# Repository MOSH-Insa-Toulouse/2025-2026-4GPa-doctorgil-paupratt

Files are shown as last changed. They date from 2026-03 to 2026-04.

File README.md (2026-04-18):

# 4A GP - Projet "Du capteur au banc de test" - I4PMH21

## Sommaire

* [Objectif du projet](#objectif-du-projet)
* [Philosophie du projet : Sobriété et Efficacité](#philosophie-du-projet--sobriété-et-efficacité)
* [Livrables](#livrables)
* [LTSpice](#ltspice)
* [KiCad](#kicad)
* [Shield](#shield)
* [Code Arduino](#code-arduino)
* [Application Android](#application-android)
* [Datasheet](#datasheet)
* [Conclusion et Bilan Critique](#conlcusion-et-bilan-critique)

---

## Objectif du projet

Dans le cadre d'un cours dispensé lors du 2<sup>nd</sup> semestre de 4<sup>ème</sup> année de Génie Physique à l'INSA de Toulouse, il nous a été proposé de réaliser un **capteur low-tech à base de graphite**, puis d'en faire une analyse critique argumentée pour en cerner les potentialités mais également pour évoquer des solutions d'amélioration. Ainsi, ce projet nous a permis de balayer l'ensemble du domaine ; du capteur jusqu'à la réalisation d'une **datasheet** et du **banc de test**.

---
## Philosophie du projet : Sobriété et Efficacité
Face à l'urgence climatique et à la demande croissante de systèmes à faible empreinte carbone, ce projet s'inscrit dans une démarche de **sobriété technologique**. Simplifier les composants pour les rendre plus efficaces énergétiquement reste un défi majeur de l'ingénierie moderne.

Si la réalisation de capteurs à haute sensibilité possède une forte valeur ajoutée, il est primordial de questionner nos besoins réels : avons-nous systématiquement besoin d'un capteur ultra-précis s'il consomme davantage ? Ou un capteur plus simple, adapté à l'usage final, est-il suffisant ?

Le choix d'un **capteur graphite "low-tech"** illustre ce compromis (trade-off) entre précision et consommation. Plutôt que de viser la performance absolue au prix d'une complexité accrue, nous avons privilégié une solution optimisée, cohérente avec les ressources disponibles et les exigences réelles du cahier des charges.

---

## Livrables

L'ensemble du projet comprend les éléments suivants :

* **Un shield PCB** branché à une board **Arduino UNO** sur lequel nous retrouverons différents composants tels que :
    * Un capteur graphite
    * Un circuit d'amplification transimpédance
    * Un module Bluetooth
    * Un encodeur rotatoire
    * Un potentiomètre digital (*qui vient remplacer la résistance R2 du circuit d'amplification*)
    * Un capteur de contrainte commercial
* **Une simulation LTSpice** du circuit transimpédance
* **Un fichier KiCad** du shield avec l'ensemble des composants cités en amont
* **Un code Arduino** qui gère le fonctionnement et les communications des modules avec la board
* **Un fichier APK Android** (conçue à l'aide du site *MIT APP Inventor*) qui permet, à partir d'un smartphone Android, de gérer l'interface avec le shield Arduino UNO par le biais d'une communication Bluetooth
* **La datasheet** du capteur graphite

> [!TIP]
> **Conseil de lecture** : Pour une compréhension optimale du projet, commencez par consulter la **Datasheet** qui résume les performances théoriques avant d'explorer les fichiers de conception KiCad.
---

## LTSpice

Afin de valider la faisabilité du projet et d'anticiper le comportement dynamique de notre système, nous avons simulé la chaîne de conditionnement sous LTSpice. Le défi majeur réside dans l'impédance extrêmement élevée du capteur (de l'ordre du $G\Omega$), qui génère des courants infimes, de l'ordre du nanoampère ($nA$). Pour rendre ce signal exploitable par un microcontrôleur, il est impératif de le filtrer contre les bruits parasites et de l'amplifier de manière significative. Le montage de transimpédance présenté ci-dessous remplit cette fonction critique :

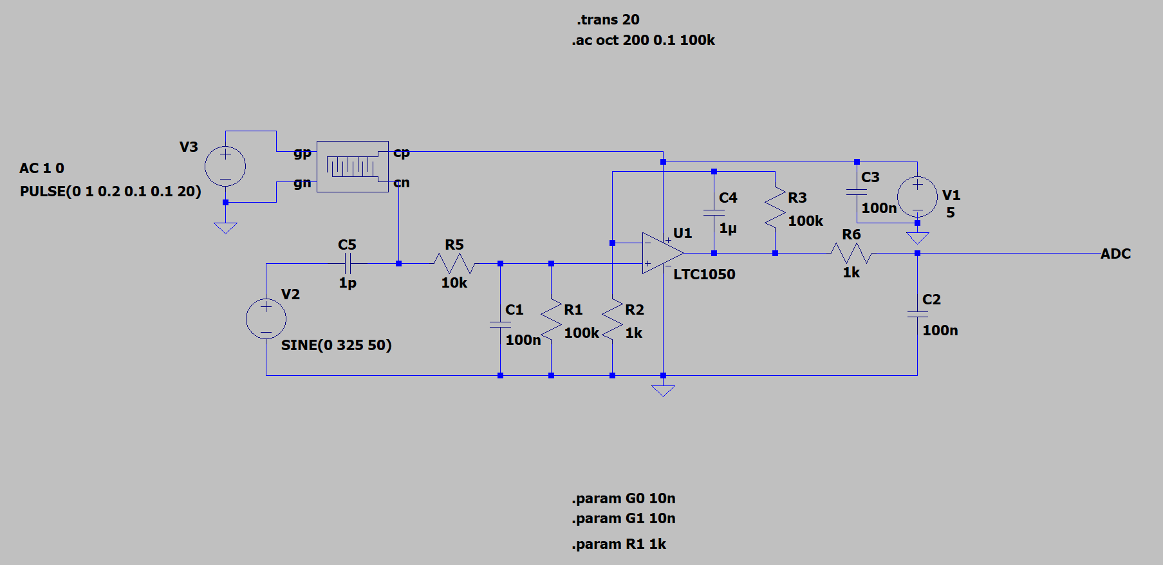
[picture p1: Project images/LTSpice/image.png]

*Circuit d'amplification/atténuation*

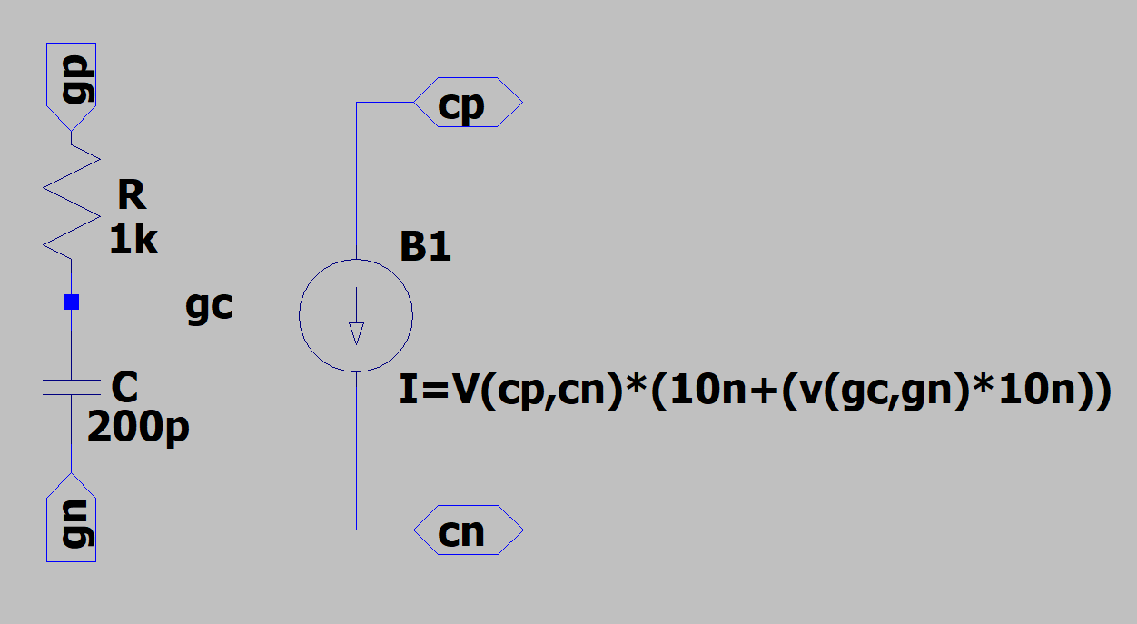
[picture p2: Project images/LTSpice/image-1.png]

*Modélisation du capteur*

Ce montage se compose de trois filtres passe-bas distincts pour optimiser le rapport signal/bruit :

* **Premier étage ($R_5, C_1, R_1$)** : Filtre les bruits en courant sur le signal d'entrée induits par l'alimentation 5V (symbolisée par 'SINE' + $C_3$).
* **Deuxième étage ($C_4, R_3$)** : Réduit spécifiquement la composante de bruit à **50 Hz** induite par le réseau électrique ambiant.
* **Troisième étage ($R_6, C_2$)** : Placé en sortie de l'amplificateur, il atténue le bruit thermique et intrinsèque du circuit.

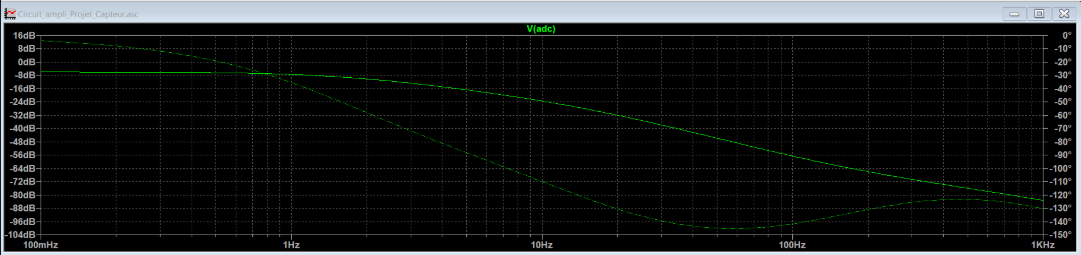
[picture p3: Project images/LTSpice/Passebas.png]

*Atténuation d'environ 46 dB à 50 Hz. Le comportement global du circuit est bel est bien passe-bas.*

Pour extraire la valeur de la résistance du capteur $R_c$ à partir de la tension mesurée $V_{adc}$, nous avons modélisé le circuit en régime statique (Basse Fréquence). 

En considérant l'AOP comme idéal en régime linéaire ($V_+ = V_-$) et en appliquant le théorème de **Millman**, nous obtenons les relations suivantes :

- #### Expression de $V_+$ (Diviseur de tension)
    $$V_+ = \frac{R_1}{R_c + R_1 + R_5} \cdot V_{cc}$$

- #### Expression de $V_-$ (Théorème de Millman)
    Comme l'entrée est reliée à la masse via $R_2$ :

    $$V_- = \frac{\frac{V_{out}}{R_3} + \frac{0}{R_2}}{\frac{1}{R_3} + \frac{1}{R_2}} = V_+$$

- #### Équation finale de la résistance $R_c$
    En posant $V_{out} = V_{adc}$ et en isolant $R_c$, nous arrivons à la formule de transfert utilisée dans le code Arduino :

    $$R_c = R_1 \cdot \frac{V_{cc}}{V_{adc}} \cdot \left(1 + \frac{R_3}{R_2}\right) - R_1 - R_5$$

Cette équation permet au microcontrôleur de convertir en temps réel la tension lue sur la broche analogique en une valeur de résistance physique exploitable pour la datasheet.

### Analyse des simulations et dimensionnement

La simulation nous a permis d'optimiser deux paramètres critiques : le filtrage du bruit secteur et la dynamique de mesure.

#### 1. Optimisation du filtrage (C4 et R3)
L'étude fréquentielle montre l'impact direct des composants sur la qualité du signal :
* **Fréquence de coupure** : Plus $C_4$ est petit, plus la fréquence de coupure $f_c = \frac{1}{2\pi R_3 C_4}$ est élevée, ce qui réduit l'efficacité du filtrage des parasites à **50 Hz**.
* **Gain du filtre** : La résistance $R_2$ permet d'ajuster le décalage vertical du signal pour l'adapter à la fenêtre de lecture.

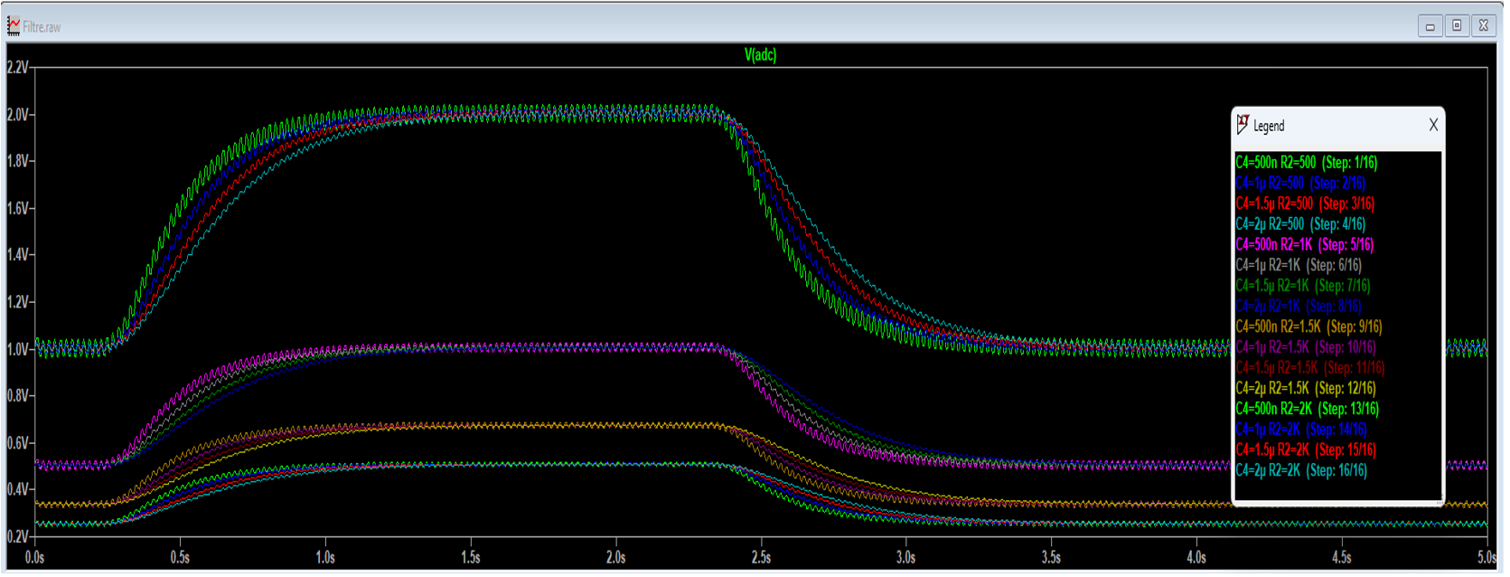
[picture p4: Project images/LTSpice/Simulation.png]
Graphique de simulation LTSpice

*Simulation de l'influence de C4 et R3 sur la stabilisation du signal.*

#### 2. Stratégie de Calibration et Plage Dynamique
Pour éviter la saturation de l'ADC de l'Arduino (limité à 5V), nous avons conçu un système de réglage de gain flexible :

* **Problématique** : La résistance des capteurs graphite varie énormément selon le dépôt. Un courant $I_{sens}$ trop élevé peut saturer l'amplificateur à 5V, rendant toute variation de pression invisible.
* **Solution Manuelle** : L'utilisateur peut ajuster dynamiquement le gain via le **potentiomètre numérique** en utilisant l'**encodeur rotatif**. 
* **Objectif** : L'utilisateur tourne l'encodeur pour ramener le signal au repos vers **2,5V** (valeur brute de 512 sur l'ADC). Cela place le point de fonctionnement au milieu de l'échelle de mesure, offrant une marge de manœuvre maximale pour observer les variations sans écrêtage.

---
## KiCad

### Conception du Shield

Afin de concevoir un **shield PCB** conforme au cahier des charges de l'UF **I4PMH21**, nous avons développé un prototype virtuel sous **KiCad**. Cette phase de conception a permis d'intégrer l'ensemble des contraintes électroniques, mécaniques et physiques liées aux composants utilisés.

La première étape a consisté à élaborer la **saisie de schéma** (*schematic*) regroupant l'intégralité des modules :

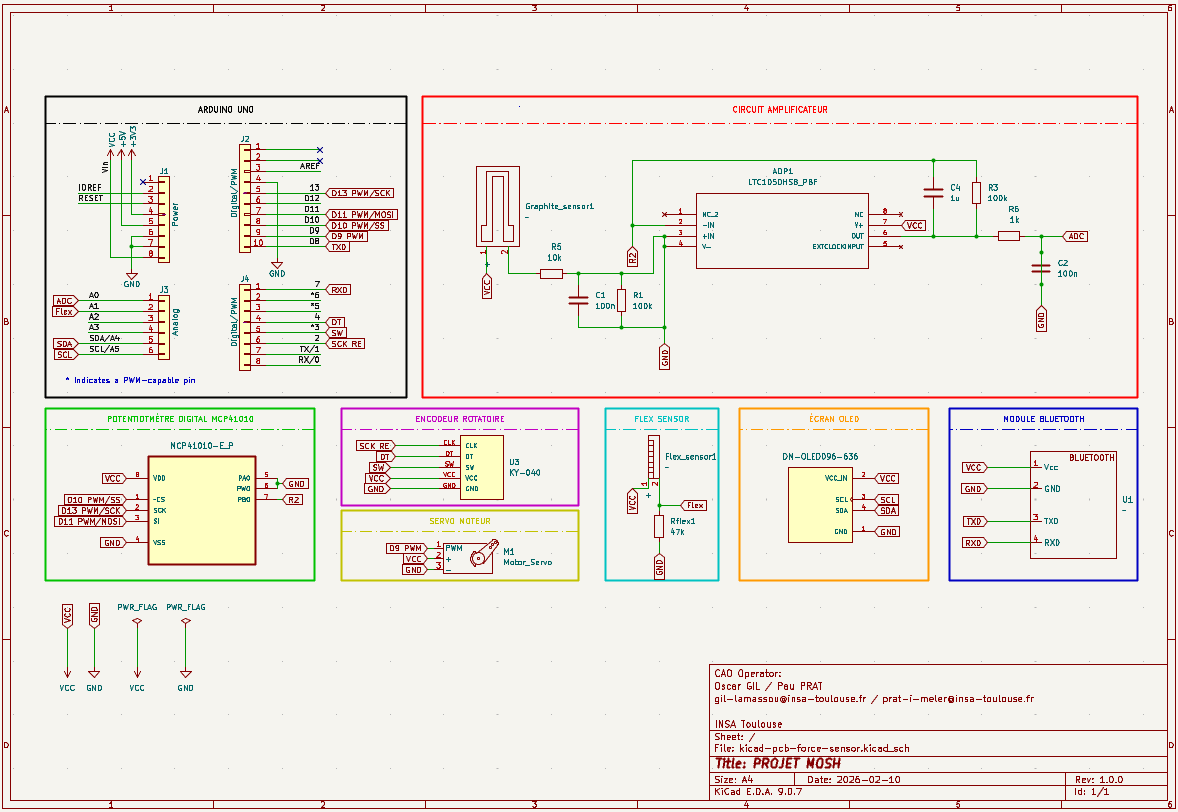
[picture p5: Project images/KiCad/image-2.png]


### Routage du PCB (Layout)

Une fois le schéma validé, nous avons procédé au **routage du PCB**. L'enjeu principal a été la gestion de l'intégrité du signal dans un environnement mixte (analogique/numérique) :

* **Plan de masse** : Mise en place d'un plan de masse continu pour minimiser l'inductance de boucle et assurer une référence stable.
* **Isolation** : Séparation physique des pistes à haute impédance (liées au capteur graphite) pour limiter les couplages capacitifs.
* **Contraintes mécaniques** : Alignement des connecteurs pour un embrochage parfait sur l'Arduino UNO.

Pour maintenir l'intégrité du plan de masse et respecter les contraintes d'espace, nous avons opté pour la mise en place d'un **strap externe (jumper)**. Cette solution a permis de finaliser les connexions tout en garantissant une isolation optimale entre les pistes critiques.

Le design final du shield est présenté ci-dessous :

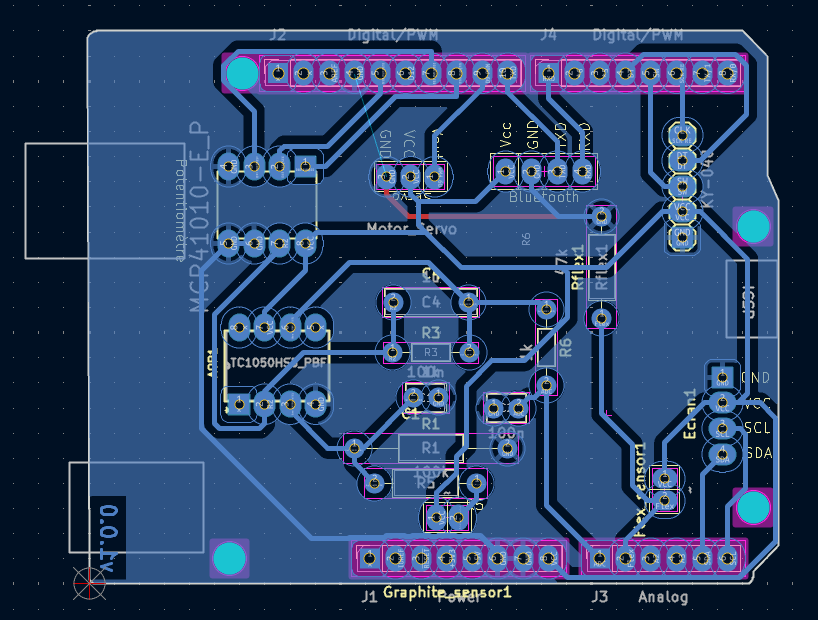
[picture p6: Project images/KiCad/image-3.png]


### Rendu 3D du Shield

Nous avons généré un rendu 3D du PCB pour visualiser l'encombrement final et l'agencement des composants. Voici une vue de dessus du projet :

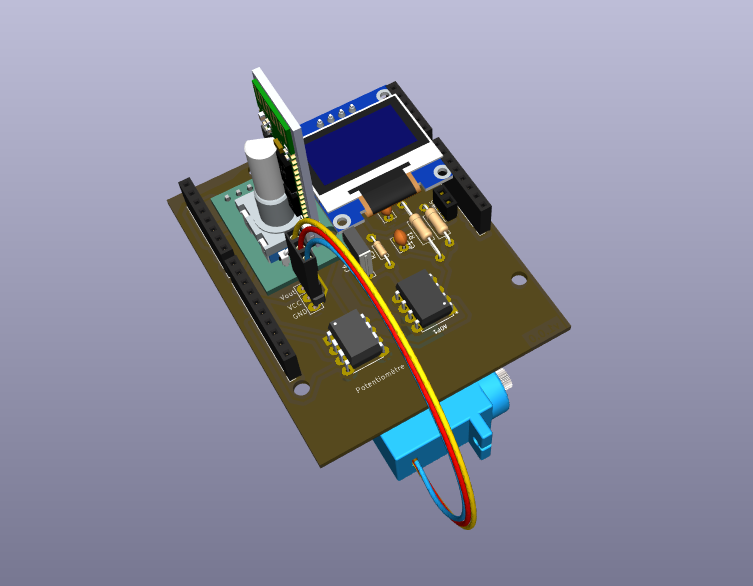
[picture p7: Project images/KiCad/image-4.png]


> [!NOTE]
> **Ajustement des modèles 3D** : Vous remarquerez peut-être des chevauchements visuels sur le rendu. Cela s'explique par l'usage de modèles CAO (fichiers `.step`) standards dont l'encombrement diffère légèrement des composants réels soudés sur le banc de test. L'empreinte au sol (*footprint*) sur le cuivre est cependant parfaitement conforme aux composants physiques.

## Shield
Une fois la conception validée, nous avons procédé à la fabrication physique du shield sur une plaque d'époxy cuivrée à l'aide de Mme. Catherine Crouzet. Le processus de prototypage rapide a suivi les étapes classiques de la photogravure :

* **Insolation** : Transfert du typon (généré sous KiCad) sur la plaque photosensible via une exposition aux UV.

* **Révélation** : Élimination de la résine non exposée à l'aide d'un révélateur chimique.

* **Gravure** : Passage dans une solution de perchlorure de fer pour dissoudre le cuivre non protégé et révéler les pistes.

Après le nettoyage de la carte, nous avons procédé à l'assemblage. Cette étape a nécessité une grande précision, notamment pour le perçage des vias et le soudage des composants traversants (THT) et CMS, en veillant scrupuleusement au respect des contraintes de température pour ne pas endommager le capteur graphite.

> [!WARNING]
> **Points de vigilance (Soudure)** : Lors de l'assemblage, une attention extrême doit être portée à la qualité des soudures. Des micro-courts-circuits ou des contacts intermittents ("soudures sèches") ont été identifiés lors de nos tests initiaux, perturbant la stabilité du signal. Un nettoyage rigoureux et une vérification systématique au multimètre sont indispensables.

> [!NOTE]
> **Évolution du projet (Servomoteur)** : Bien que prévu initialement dans la conception du shield, le servomoteur n'a finalement pas été implémenté. Ce choix s'explique par des contraintes de temps et par le fait que le banc de test s'est révélé parfaitement fonctionnel et suffisant sans le servo pour valider les mesures du capteur.

## Code Arduino

En parallèle de la partie *KiCad*, nous avons développé le [Code Arduino](./Arduino/Code/ProjetMosh/ProjetMosh.ino) permettant la communication des composants avec l'**Arduino UNO**, voici les fonctionnalités principales :

* **Acquisition Analogique** : Lecture haute impédance et conversion du signal en résistance.
* **Contrôle du Gain via Encodeur** : Utilisation de l'**encodeur rotatif** pour incrémenter ou décrémenter la valeur du potentiomètre numérique. Cette interface permet à l'utilisateur de calibrer manuellement le capteur en temps réel.
* **Gestion du Potentiomètre Digital** : Communication via le bus I2C pour mettre à jour la résistance de contre-réaction ($R_2/R_g$) dès qu'une rotation de l'encodeur est détectée.
* **Interface Bluetooth** : Transmission des données vers l'application Android pour un monitoring sans fil.

> [!TIP]
> **Structure du code** : Le code est organisé de manière non-bloquante (utilisation de `millis()` au lieu de `delay()`) pour garantir une réactivité maximale de la liaison Bluetooth et de l'encodeur.

---

## Application Android
Nous avons réalisé une application mobile à l'aide de **MIT App Inventor**.  Ce dashboard permet non seulement de lire les valeurs du capteur graphite en temps réel, mais constitue également un outil d'acquisition de données complet.

> Le code de programmation est disponibles ici : **[Accéder au code de l'application](./Application/Code%20apk)**.

* **Liaison Bluetooth** : Connexion simplifiée avec le module HC-05 présent sur le shield.
* **Graphique Dynamique** : Visualisation temporelle de la résistance pour identifier la sensibilité du capteur à la déformation.

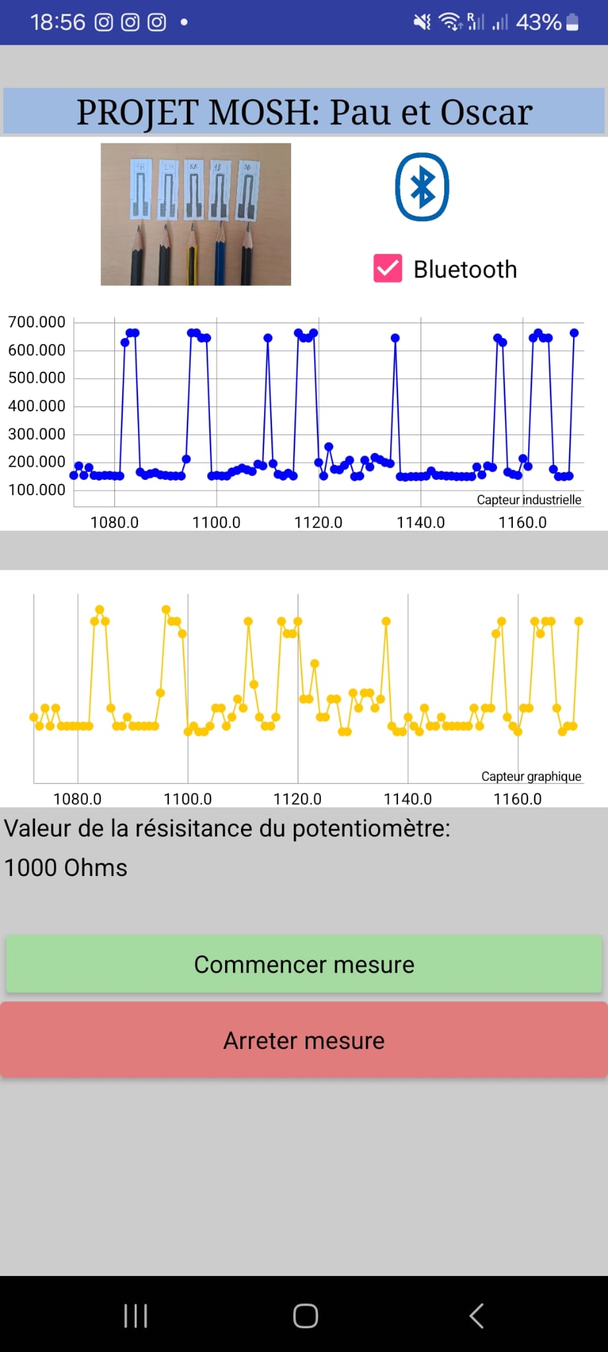
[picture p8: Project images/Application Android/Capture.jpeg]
Interface Application Android


*Interface utilisateur pour la visualisation des données en temps réel.*

---
## Datasheet

La rédaction de la **datasheet** repose sur une série de mesures expérimentales effectuées grâce à un banc de test dédié.

Le banc de test, imprimé en 3D, utilise 7 demi-disques (Ø 1cm à 5cm) pour simuler des déformations contrôlées. Nous avons testé une gamme de capteurs allant du **2H au 3B** pour identifier le meilleur compromis entre conductivité initiale et sensibilité à la flexion.

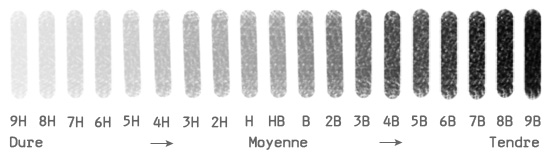
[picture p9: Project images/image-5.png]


*Classification des nuances de graphite : de la mine dure (H) à la mine tendre (B).*

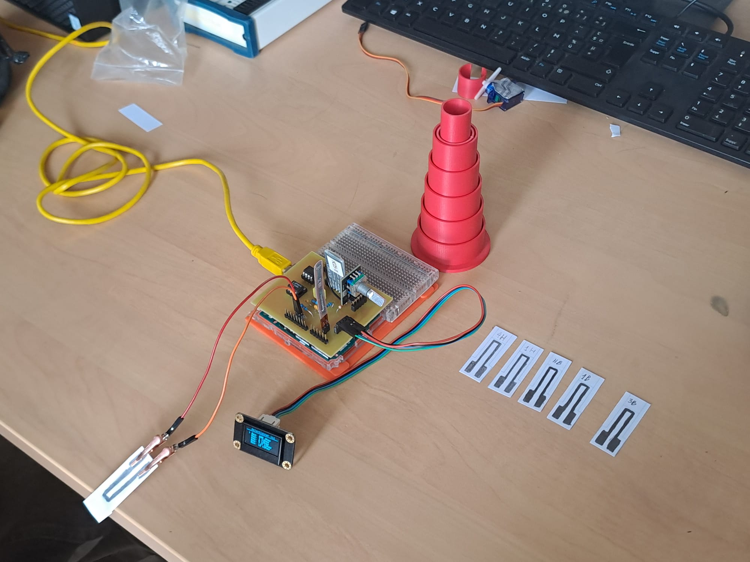
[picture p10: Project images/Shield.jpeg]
Shield

*Montage complet*

 **Documentation technique** : Le rapport complet des performances est disponible ici : 
> 📄 **[Consulter la Datasheet (PDF)](./Caractérisation%20et%20Datasheet/Datasheet.pdf)**

> [!NOTE]
> **Sélection des échantillons** : Certains capteurs présentant des valeurs aberrantes ou une instabilité trop marquée ont été écartés de l'analyse finale afin de garantir la cohérence des courbes de tendance.

> [!WARNING]
> **Limites expérimentales** : La reproductibilité des mesures s'est avérée délicate. Plusieurs facteurs ont influencé les résultats :
> * **Variation de densité** du graphite lors du dépôt manuel.
> * **Dégradation mécanique** de la couche de graphite au fil des tests.
> * **Contacts électriques** instables en fin de série.

## Conclusion et Bilan Critique

Ce projet constitue une preuve de concept réussie : il démontre qu’un matériau aussi rudimentaire que le graphite déposé sur papier peut être transformé en un **capteur de déformation (strain sensor)** fonctionnel grâce à une chaîne de conditionnement électronique optimisée.

### Synthèse des résultats
Nos simulations et tests physiques ont validé la réponse piézorésistive attendue : la résistance augmente en extension et diminue en compression. Le système complet (Capteur -> Shield -> Arduino -> Android) est pleinement opérationnel pour du monitoring en temps réel.

Cependant, la reproductibilité demeure le principal défi technologique. L’hétérogénéité du dépôt manuel de graphite et les aléas liés au prototypage artisanal du PCB (gravure chimique, perçage et soudures) limitent la fiabilité des mesures.

### Perspectives : La force du Low-Tech
L'intérêt majeur de ce projet réside dans sa **valeur pédagogique**. Il prouve qu'un système d'instrumentation complet peut être conçu avec des ressources limitées. Plutôt que de complexifier le capteur, l'enjeu futur serait de rendre le processus de dépôt du graphite plus robuste et automatisé.

**En conclusion**, ce projet nous a permis d'appréhender l'ensemble du cycle de vie d'un produit électronique, de la physique fondamentale du capteur jusqu'à l'interface utilisateur mobile.

---
## Remerciements

Nous tenons à remercier Mme. Crouzet et M. Grisolia pour leur encadrement précieux et leurs conseils techniques lors de la phase de conception et de fabrication tout au long de ce projet.

---

## Contact

Si vous avez des questions concernant ce projet ou l'utilisation du shield, n'hésitez pas à nous contacter :

* **Oscar GIL** : [gil-lamassou@insa-toulouse.fr](mailto:gil-lamassou@insa-toulouse.fr)
* **Pau PRAT** : [prat-i-meler@insa-toulouse.fr](mailto:prat-i-meler@insa-toulouse.fr)

---

[↑ Retour au sommaire](#sommaire)

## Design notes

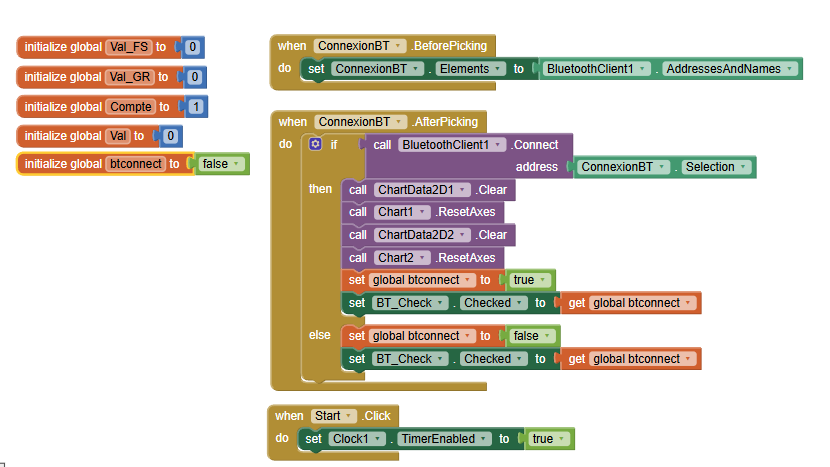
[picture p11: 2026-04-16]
Application/Code apk/codeAPK1.png

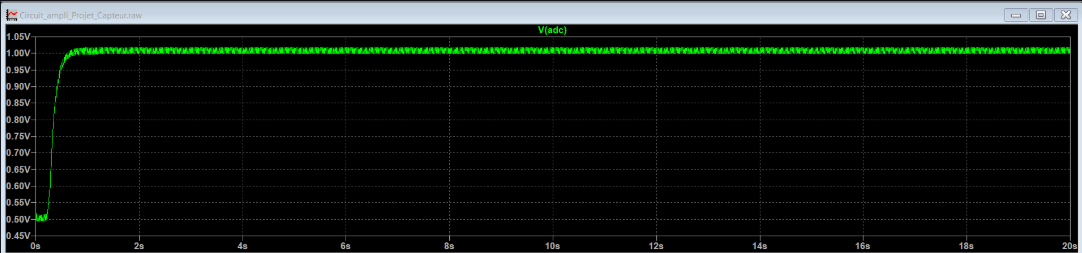
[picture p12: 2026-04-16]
Project images/LTSpice/Gain.png

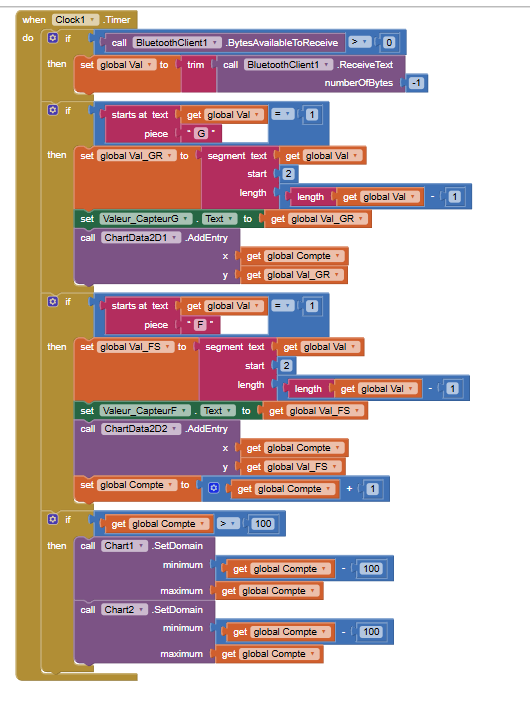
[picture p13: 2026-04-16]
Application/Code apk/codeAPK3.png

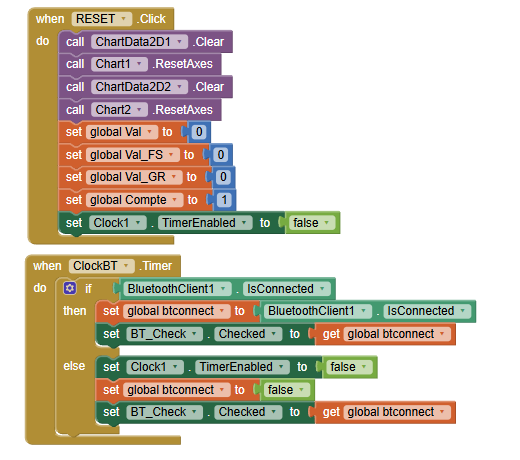
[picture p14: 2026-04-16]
Application/Code apk/codeAPK2.png

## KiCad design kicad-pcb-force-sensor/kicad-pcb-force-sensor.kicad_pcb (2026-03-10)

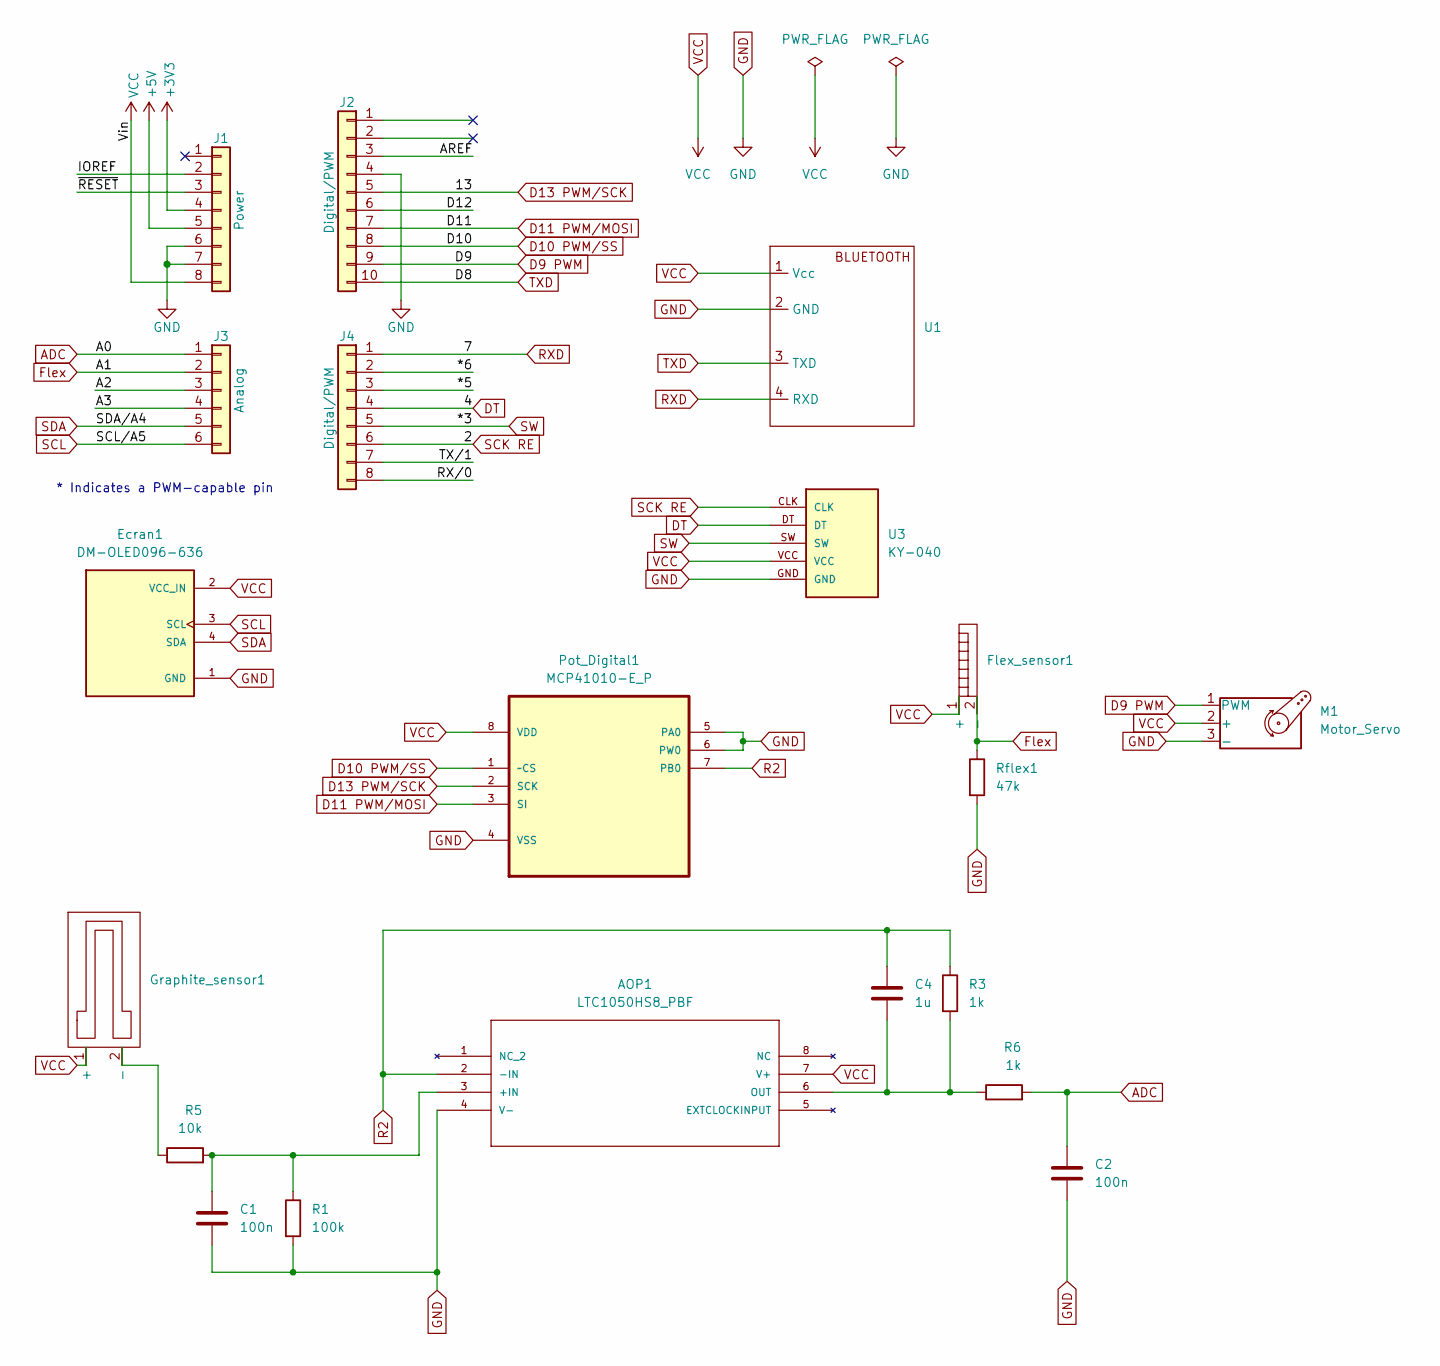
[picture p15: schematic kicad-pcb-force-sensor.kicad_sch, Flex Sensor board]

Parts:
AOP1: LTC1050HS8_PBF
C1, C2: 100n; C_Disc_D3.8mm_W2.6mm_P2.50mm
C4: 1u; C_Rect_L9.0mm_W2.5mm_P7.50mm_MKT
Ecran1: DM-OLED096-636; MODULE_DM-OLED096-636
Flex_sensor1: Flex
Graphite_sensor1: Graphite_sensor_emprunt
J1: Power; PinSocket_1x08_P2.54mm_Vertical
J2: Digital/PWM; PinSocket_1x10_P2.54mm_Vertical
J3: Analog; PinSocket_1x06_P2.54mm_Vertical
J4: Digital/PWM; PinSocket_1x08_P2.54mm_Vertical
M1: Motor_Servo; Servo
Pot_Digital1: MCP41010-E_P; MCP41010
R1: 100k; R_Axial_DIN0207_L6.3mm_D2.5mm_P15.24mm_Horizontal
R3, R6: 1k; R_Axial_DIN0204_L3.6mm_D1.6mm_P7.62mm_Horizontal
R5: 10k; R_Axial_DIN0207_L6.3mm_D2.5mm_P10.16mm_Horizontal
Rflex1: 47k; R_Axial_DIN0207_L6.3mm_D2.5mm_P10.16mm_Horizontal
U1: BT_HC05
U3: KY-040; KY-040-PORT

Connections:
+3V3: J1.4
+5V: J1.5
/*5: J4.3
/*6: J4.2
/A2: J3.3
/A3: J3.4
/AREF: J2.3
/D12: J2.6
/IOREF: J1.2
/RX/0: J4.8
/TX/1: J4.7
/~RESET: J1.3
ADC: C2.2, J3.1, R6.2
D9 PWM: J2.9, M1.1 (PWM)
D10 PWM/SS: J2.8, Pot_Digital1.1 (~CS)
D11 PWM/MOSI: J2.7, Pot_Digital1.3 (SI)
D13 PWM/SCK: J2.5, Pot_Digital1.2 (SCK)
DT: J4.4, U3.DT
Flex: Flex_sensor1.2 (-), J3.2, Rflex1.1
GND: AOP1.4 (V-), C1.1, C2.1, Ecran1.1 (GND), J1.6, J1.7, J2.4, M1.3 (-), Pot_Digital1.4 (VSS), Pot_Digital1.5 (PA0), Pot_Digital1.6 (PW0), R1.2, Rflex1.2, U1.2 (GND), U3.GND
unnamed: AOP1.3 (+IN), C1.2, R1.1, R5.2
unnamed: AOP1.6 (OUT), C4.1, R3.2, R6.1
unnamed: Graphite_sensor1.2 (-), R5.1
R2: AOP1.2 (-IN), C4.2, Pot_Digital1.7 (PB0), R3.1
RXD: J4.1, U1.4 (RXD)
SCK RE: J4.6, U3.CLK
SCL: Ecran1.3 (SCL), J3.6
SDA: Ecran1.4 (SDA), J3.5
SW: J4.5, U3.SW
TXD: J2.10, U1.3 (TXD)
VCC: AOP1.7 (V+), Ecran1.2 (VCC_IN), Flex_sensor1.1 (+), Graphite_sensor1.1 (+), J1.8, M1.2 (+), Pot_Digital1.8 (VDD), U1.1 (Vcc), U3.VCC

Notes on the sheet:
* Indicates a PWM-capable pin

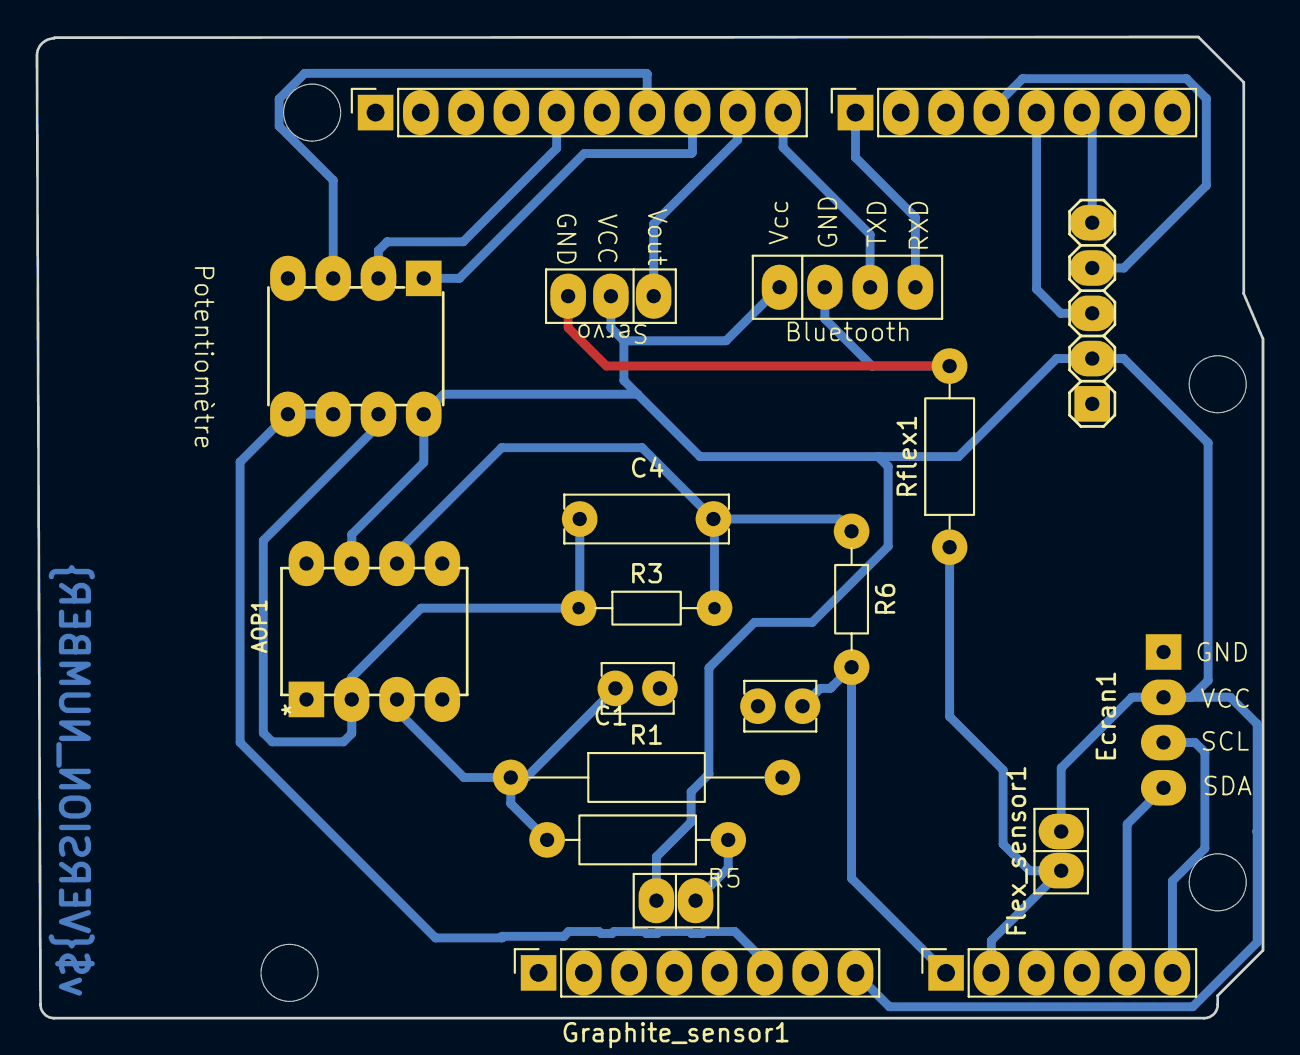
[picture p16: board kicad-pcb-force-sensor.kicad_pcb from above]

Board: 2 copper layers, 68.8 x 55.0 mm, 24 parts (0 on the bottom side), 19 nets.

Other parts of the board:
MH1, MH2, MH3, MH4: MountingHole_3.2mm

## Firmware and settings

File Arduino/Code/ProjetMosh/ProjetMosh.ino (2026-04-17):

/*------------------------------- LIBRAIRIES UTILISEES -------------------------------*/

#include <Wire.h>
#include <Adafruit_GFX.h>
#include <Adafruit_SSD1306.h>
#include <SPI.h>
#include <SoftwareSerial.h>

/*------------------------------- DECLARATIONS ET DEFINITIONS DIVERSES -------------------------------*/


// Définition des pins pour les capteurs à étudier

#define GRAPH_SENSOR A0 //Capteur graphite sur l'entrée analogique A0
#define FLEX_SENSOR A1 //Capteur commercial sur l'entrée analogique A1


// Définition des pins de l'encodeur rotatoire

#define encoderPinA 2   //CLK
#define encoderPinB 4  
#define Switch 3



// Définition des broches RXD et TXD du module BT HC-05
#define RX_PIN 8 // Broche TXD du module BT connecté à la broche 7 de l'arduino (IL SONT INVERSEE!!!!) pas de communication sinon
#define TX_PIN 7 // Broche RXD du module BT connecté à la broche 8 de l'arduino


// Déclaration d'un objet de type SoftwareSerial pour poourvoir communiquer avec le BT
SoftwareSerial Bluetooth(RX_PIN, TX_PIN); //Définition du software serial


// Déclaration de l'écran OLED avec la bibliothèque AdaFruit

#define SCREEN_WIDTH 128
#define SCREEN_HEIGHT 64
#define OLED_RESET -1
#define OLED_ADDR 0x3C
Adafruit_SSD1306 display(SCREEN_WIDTH, SCREEN_HEIGHT, &Wire, OLED_RESET);



// Menu de l'écran OLED

const char* menuItems[] = {"Res: 200 Ohms", "Res: 1 kOhms", "Res: 5 kOhms", "Res: 7.5 kOhms", "Res: 10 kOhms"};
const int totalItems = 5;
int currentSelection = 0;



// Déclaration pour le potentiomètre digital

const byte csPin           = 10;      //Active le potentiomètre digitale, si LOW le MCP écoute le SPI
const int  maxPositions    = 256;    
const long rAB             = 10000.0;  //Résistance totale du potentiomètre, MCP41010 --> 10kOhm
const byte rWiper          = 52;    
const byte pot0Write       = 0x11;    // pot0 addr, commande SPI pour écrire dans le potentiomètre
const byte pot0Shutdown    = 0x21;    // pot0 shutdown, commande SPI pour éteindre le potentiomètre
int pos_res_variable = 5; // Fixe la résistance initiale du potentiomètre digital



// Déclaration pour le flex sensor et le capteur graphite

const float VCC = 5.0;                      // Tension alimentation
const float flexR_DIV = 27000.0;            // Résistance fixe du pont diviseur de tension qui accompagne le FlexSensor
const float flexflatResistance = 25000.0;   // Résistance FlexSensor à plat
const float flexbendResistance = 100000.0;  // Résistance FlexSensor à 90 dégrés
float tension_graphite = 0;        // Tension mesuré par le capteur graphite
float tension_flex = 0;            // Tension mesuré par le FlexSensor
long resistance_variable = 0;      // Résistance du MCP
float resistance_graphite = 0;     // Résistance du capteur graphene
long resistance_flex = 0;          // Résistance FlexSensor



 

// Varisables du movement de l'éncodeur

volatile long encoderValue = 0;
long lastEncoderValue = -1;
unsigned long lastButtonTime = 0;
const int debounceDelay = 200;

volatile unsigned long lastInterruptTime = 0;



void setup() {

  Serial.begin(9600);
  Bluetooth.begin(9600);

  // Initialisation des pins

  pinMode(encoderPinA, INPUT);
  pinMode(encoderPinB, INPUT);
  pinMode(Switch, INPUT);

  pinMode(GRAPH_SENSOR, INPUT);
  pinMode(FLEX_SENSOR, INPUT);

  
  attachInterrupt(digitalPinToInterrupt(encoderPinA), updateEncoder, FALLING);

  Serial.println("Hola que tal");

  // Initialisation de l'écran OLED

  if(!display.begin(SSD1306_SWITCHCAPVCC, OLED_ADDR)) {    //Si no reconoce OLED
  Serial.println("No reconozco LED");
    for(;;);
  }
  display.clearDisplay();
  display.setTextColor(SSD1306_WHITE);
  drawMenu(); // Dibujo inicial
  Serial.println("OLED dibujao");
  
  // Initialisation de la communication avec le potentiomètre digital

  digitalWrite(csPin, HIGH);  // Le dispositif SPI n'est pas sélectioné pour éviter des activations accidentales --> pas de communication  
  pinMode(csPin, OUTPUT);          
  SPI.begin();

  Serial.println("--- SETUP COMPLETADO, ENTRANDO AL LOOP ---");
}



void loop() {

  // Movement de l'éncodeur
  if (encoderValue != lastEncoderValue) {

    // Circulaire!!!
    if (encoderValue >= totalItems) encoderValue = 0;
    if (encoderValue < 0) encoderValue = totalItems - 1;

    currentSelection = encoderValue;
    lastEncoderValue = encoderValue;
    drawMenu();

  }

  // Pulsar boton
  if (digitalRead(Switch) == LOW) {

    if (millis() - lastButtonTime > debounceDelay) {
      actionbouton(currentSelection);
      lastButtonTime = millis();
      drawMenu();

    }

  }

  // Mesures des capteurs et de la résistance variable

  int valor_graph = analogRead(GRAPH_SENSOR);
  tension_graphite =  valor_graph * VCC / 1023.0;
  resistance_variable = ((rAB * pos_res_variable) / maxPositions) + rWiper;

if (tension_graphite > 0.01) {
    //resistance_graphite = ((VCC/tension_graphite)*100000*(1+(1000/resistance_variable))-100000-10000)/1000000; //Résultat en MOHMS
    resistance_graphite = ((VCC/tension_graphite)*100000*(1+(1000/resistance_variable))-100000-10000); //Résultat en OHMS
  }

  int valor_flex = analogRead(FLEX_SENSOR); 
  tension_flex = valor_flex * VCC / 1023.0;

  //resistance_flex = 0.0; 
  if (tension_flex > 0.01) {
    resistance_flex = flexR_DIV * (VCC / tension_flex - 1);
  }

  //Serial.print("Resistencia_Flex:"); Verification des donnees bt et du delay
  //Serial.println(resistance_flex);
  Bluetooth.print("F");
  Bluetooth.println(resistance_flex); //"F512"
  delay(50);  //Delay aussi du timer de lapp

  Serial.print("Resistencia_Graph:"); 
  Serial.println(resistance_graphite);

  Bluetooth.print("G");
  Bluetooth.println(resistance_graphite); //"G1023"
  delay(50);



  //if (Bluetooth.available()) {

    // Lit les données reçues depuis le module Bluetooth
   // char receivedChar = Bluetooth.read();
    // Affiche les données reçues sur le moniteur série
    //Serial.print(receivedChar);
 // }
  display.fillRect(10, 55, 100, 8, SSD1306_BLACK);
  display.setCursor(10, 55);
  display.print("Val : ");
  display.print(resistance_variable);
  display.display();

}


  
/*------------------------------- FONCTIONS UTILIES ------------------------------- */

// Fonction pour régler la valeur du potentiomètre

void setPotWiper(byte address, int value) {

  digitalWrite(csPin, LOW);
  SPI.transfer(address);
  SPI.transfer(value);
  digitalWrite(csPin, HIGH);

}



void actionbouton(int seleccion) {

  display.clearDisplay();
  display.setCursor(20, 20);
  display.setTextSize(1);

  // Aquí defines qué hace cada opción del menú

  switch (seleccion) {

    case 0: // 500
      display.println(F("Résistance de: "));
      display.println(F("200 Ohms"));
      pos_res_variable = 1;
      setPotWiper(pot0Write, pos_res_variable);
      break;

    case 1: // 1k

      display.println(F("Résistance de: "));
      display.println(F("1000 Ohms"));
      pos_res_variable = 25;
      setPotWiper(pot0Write, pos_res_variable);
      break;

    case 2: // 5k

      display.println(F("Résistance de: "));
      display.println(F("5 kOhms"));
      pos_res_variable = 128;           //7500 x 255/10000 = 128 (pas de 10k pour le 41010)
      setPotWiper(pot0Write, pos_res_variable);
      break;

    case 3: // 10k

      display.println(F("Résistance de: "));
      display.println(F("7,5 kOhms"));
      pos_res_variable = 191;
      setPotWiper(pot0Write, pos_res_variable);
      break;

    case 4: // 100k

      display.println(F("Résistance de: "));
      display.println(F("10 kOhms"));
      pos_res_variable = 255;
      setPotWiper(pot0Write, pos_res_variable);
      break;


  }

  display.display();
  delay(2000); // El mensaje dura 2 segundos

}



void updateEncoder() {
  // Leemos el tiempo actual
  unsigned long interruptTime = millis();

  // Si han pasado más de 5 milisegundos desde el último giro, es un movimiento real
  if (interruptTime - lastInterruptTime > 5) {

    if (digitalRead(encoderPinB) != digitalRead(encoderPinA)) {
      encoderValue++;
    } else {
      encoderValue--;
    }

  }
  // Guardamos el tiempo de este movimiento
  lastInterruptTime = interruptTime;
}



void drawMenu() {

  display.clearDisplay();
  display.setTextSize(1);
  display.setCursor(0, 0);
  //display.println(F("Selectionner Val"));
  //display.drawFastHLine(0, 10, 128, SSD1306_WHITE);

  for (int i = 0; i < totalItems; i++) {

    display.setCursor(0, 2 + (i * 9));
    if (i == currentSelection) {
      display.print(F("> "));
      display.print(menuItems[i]);
    } else {
      display.print(F("  "));
      display.print(menuItems[i]);
    }

  }

  display.display();
}

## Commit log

2026-02-18 Ajout du projet KICAD
    [kicad-pcb-force-sensor.kicad_pcb, kicad-pcb-force-sensor.kicad_sch]
2026-02-18 Cambio de pin prueba
    [kicad-pcb-force-sensor.kicad_sch]
2026-02-18 Pines graphic sesor
    [kicad-pcb-force-sensor.kicad_pcb, kicad-pcb-force-sensor.kicad_sch]
2026-02-18 Ground y VCC
    [kicad-pcb-force-sensor.kicad_sch]
2026-02-18 Avec pistes
    [kicad-pcb-force-sensor.kicad_pcb, kicad-pcb-force-sensor.kicad_sch]
2026-02-25 Modifier pins à 0.8mm plus détails
    [kicad-pcb-force-sensor.kicad_pcb, kicad-pcb-force-sensor.kicad_sch]
2026-03-10 GND y pins header arduino
    [kicad-pcb-force-sensor.kicad_pcb]
2026-04-11 Code Arduino + Primera modificación codigo readme
2026-04-13 partie Kicad
    [kicad-pcb-force-sensor.kicad_sch]
2026-04-13 note évolution du projet servomoteur
2026-04-15 Caractérisation et datasheet
    [Caractérisation.ods, kicad-pcb-force-sensor.kicad_sch]
2026-04-17 kicad malo borrado
    [kicad-pcb-forcesensor.kicad_pcb, kicad-pcb-forcesensor.kicad_sch]
2026-04-17 Datasheet 3
    [Caractérisation.ods]
2026-04-18 nueva datasheet
    [kicad-pcb-force-sensor.kicad_sch]
